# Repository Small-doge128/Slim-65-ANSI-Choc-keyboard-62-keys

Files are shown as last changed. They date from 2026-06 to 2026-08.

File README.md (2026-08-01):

# about

A mint sounding keyboard that's small, lightweight and thin as a cookie, also the hardest was that I used ki cad , building a keyboard and software all of that first in my life. It's going to be for my acer aspire 5. 

# features

Hot swap sockets so you can swap switches fast and easy. You can program the keys to what ever you want via QMK, if you know what are you doing. Custom 3d prnted keycaps that i designed myself except the 1u I bought those and a 3d printed case that you can use but i didn't.

# step by step tutorial for firmware

1. Download the file called slim65_default.uf2.
2. Press and hold the boot button, while holding plug a USB-C cable from your computer to the controller.
3. Now a new folder/device should pop up.
4. Put the .uf2 file into there and it should remove it self.
5. If it did now the keyboard should work enjoy.

# dimensions
PCB - 294 mm lenght and 91 mm width

# keys

it has 49-1U keys, 6-1.25U keys, 2-1.5U keys, 2-1.75U keys, 2-2.25 and  1-6.25U key total 62 keys.

# why did i create it

I created this becouse i wanted a keyboard that i would like and enjoy. It's going to be a massive upgrade from my scissor keyboard on my laptop. I chose slim and 65% keyboard becouse i want it to be compact and light weight. I also like doing projects but this one is something else.

# pictures

2026-05-09-193907_hyprshot



2026-05-09-194605_hyprshot





2026-06-12-214342_hyprshot

2026-06-12-214249_hyprshot

# demo video

https://github.com/user-attachments/assets/ab127268-83f5-4e21-8910-376c34ff119f
This was my first demo video, so excuse my english and my stuttering.

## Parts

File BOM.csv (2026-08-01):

Name | Purpose | Qty | Unit Price (USD) | Total (USD) | Distributor | Link
Keyboard PCB | Connecting all the components | 5 | 5.80 | 29.00 | JLCPCB | https://jlcpcb.com
rp2040-zero | A small brain for the whole system | 1 | 1.99 | 1.99 | Aliexpress | https://www.aliexpress.com/item/1005010194358457.html
Kailh Choc Hotswap Sockets | Socket to swap switches so much faster | 100 | 0.09 | 8.58 | Aliexpress | https://www.aliexpress.com/item/1005008879295483.html
rmRecommeKailh Choc Low Profile Keycaps Black | A bigger surface to type on | 70 | 0.26 | 18.53 | Aliexpress | https://www.aliexpress.com/item/1005009278324475.html
Kailh Choc Low Profile Switch 1350 Red | Switch for keys | 70 | 0.38 | 26.59 | Aliexpress | https://www.aliexpress.com/item/1005008806799106.html
TOTAL |  |  |  | $84.69
TOTAL (with tax & shipping) |  |  |  | $92.69

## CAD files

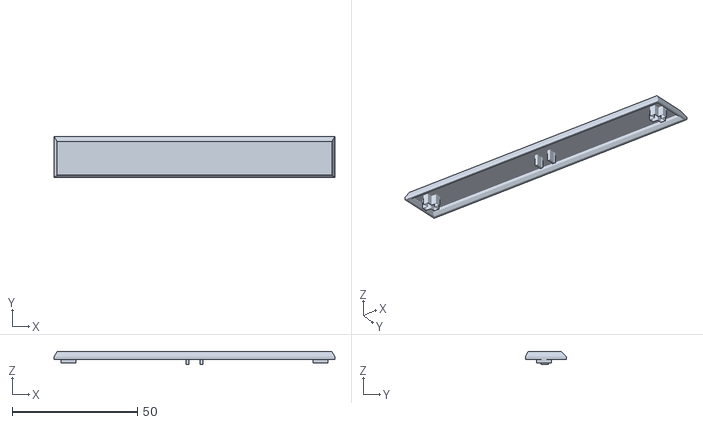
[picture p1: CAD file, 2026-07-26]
kailh choc keycaps/choc keycap 6.25 u.stl
112.0 x 16.5 x 5.00

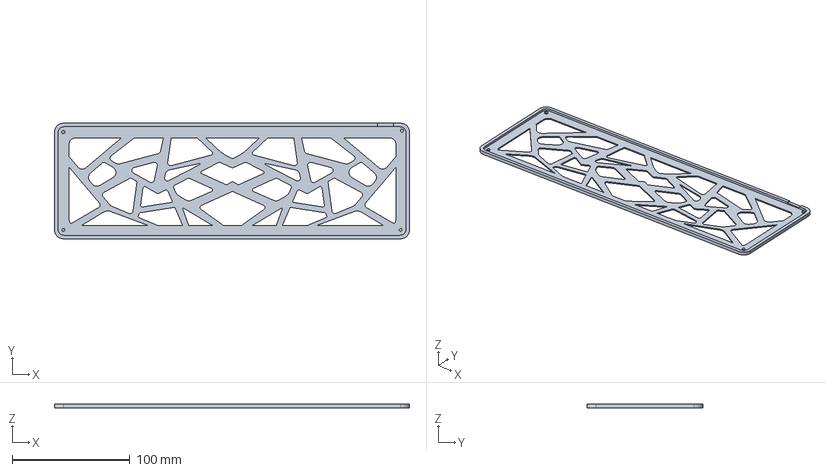
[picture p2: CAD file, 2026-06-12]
step file/Keyboard case.step
301.0 x 98.0 x 3.00 mm

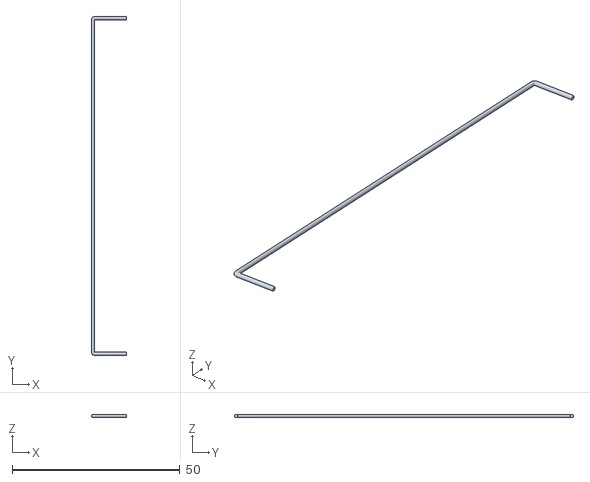
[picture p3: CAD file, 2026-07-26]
kailh choc keycaps/kailh choc stabilizer wire 6.25 u.stl
10.5 x 101.0 x 1.00

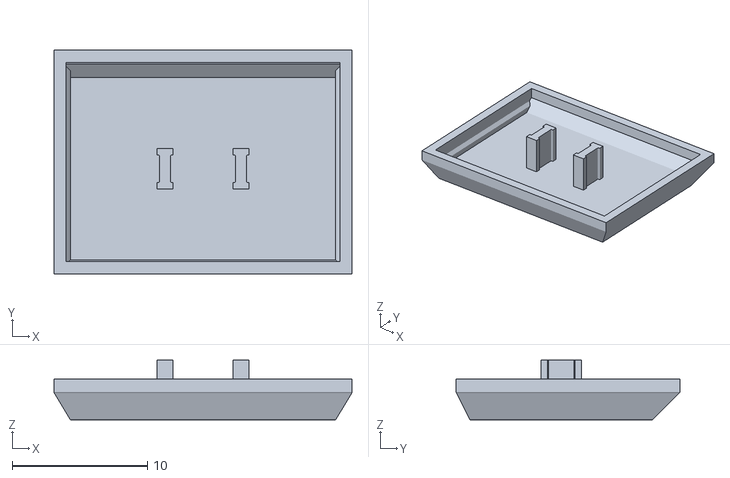
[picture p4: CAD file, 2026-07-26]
kailh choc keycaps/choc keycap 1.25 u.stl
22.0 x 16.5 x 4.40

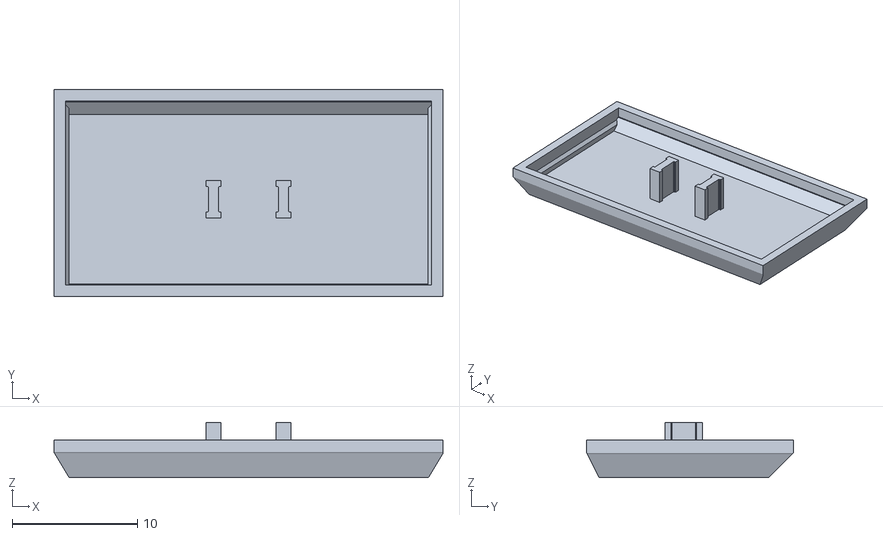
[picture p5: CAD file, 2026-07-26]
kailh choc keycaps/choc keycap 1.75 u.stl
31.0 x 16.5 x 4.40

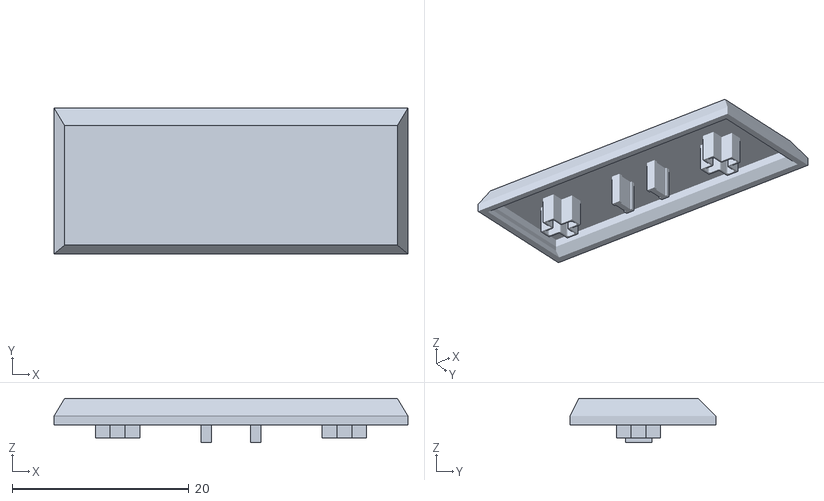
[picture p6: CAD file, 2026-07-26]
kailh choc keycaps/choc keycap 2.25 u.stl
40.0 x 16.5 x 5.00

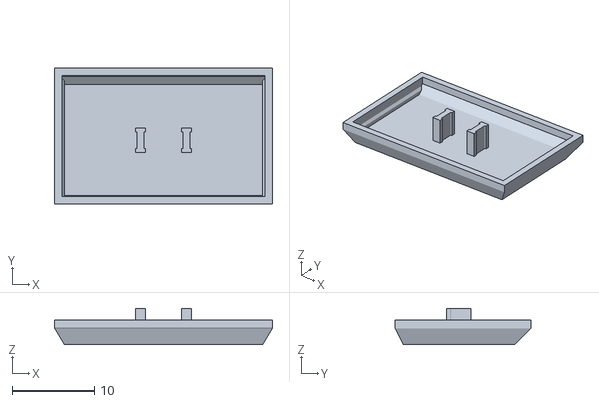
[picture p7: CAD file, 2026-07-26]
kailh choc keycaps/choc keycap 1.5 u.stl
26.5 x 16.5 x 4.40

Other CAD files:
Keyboard case.stl

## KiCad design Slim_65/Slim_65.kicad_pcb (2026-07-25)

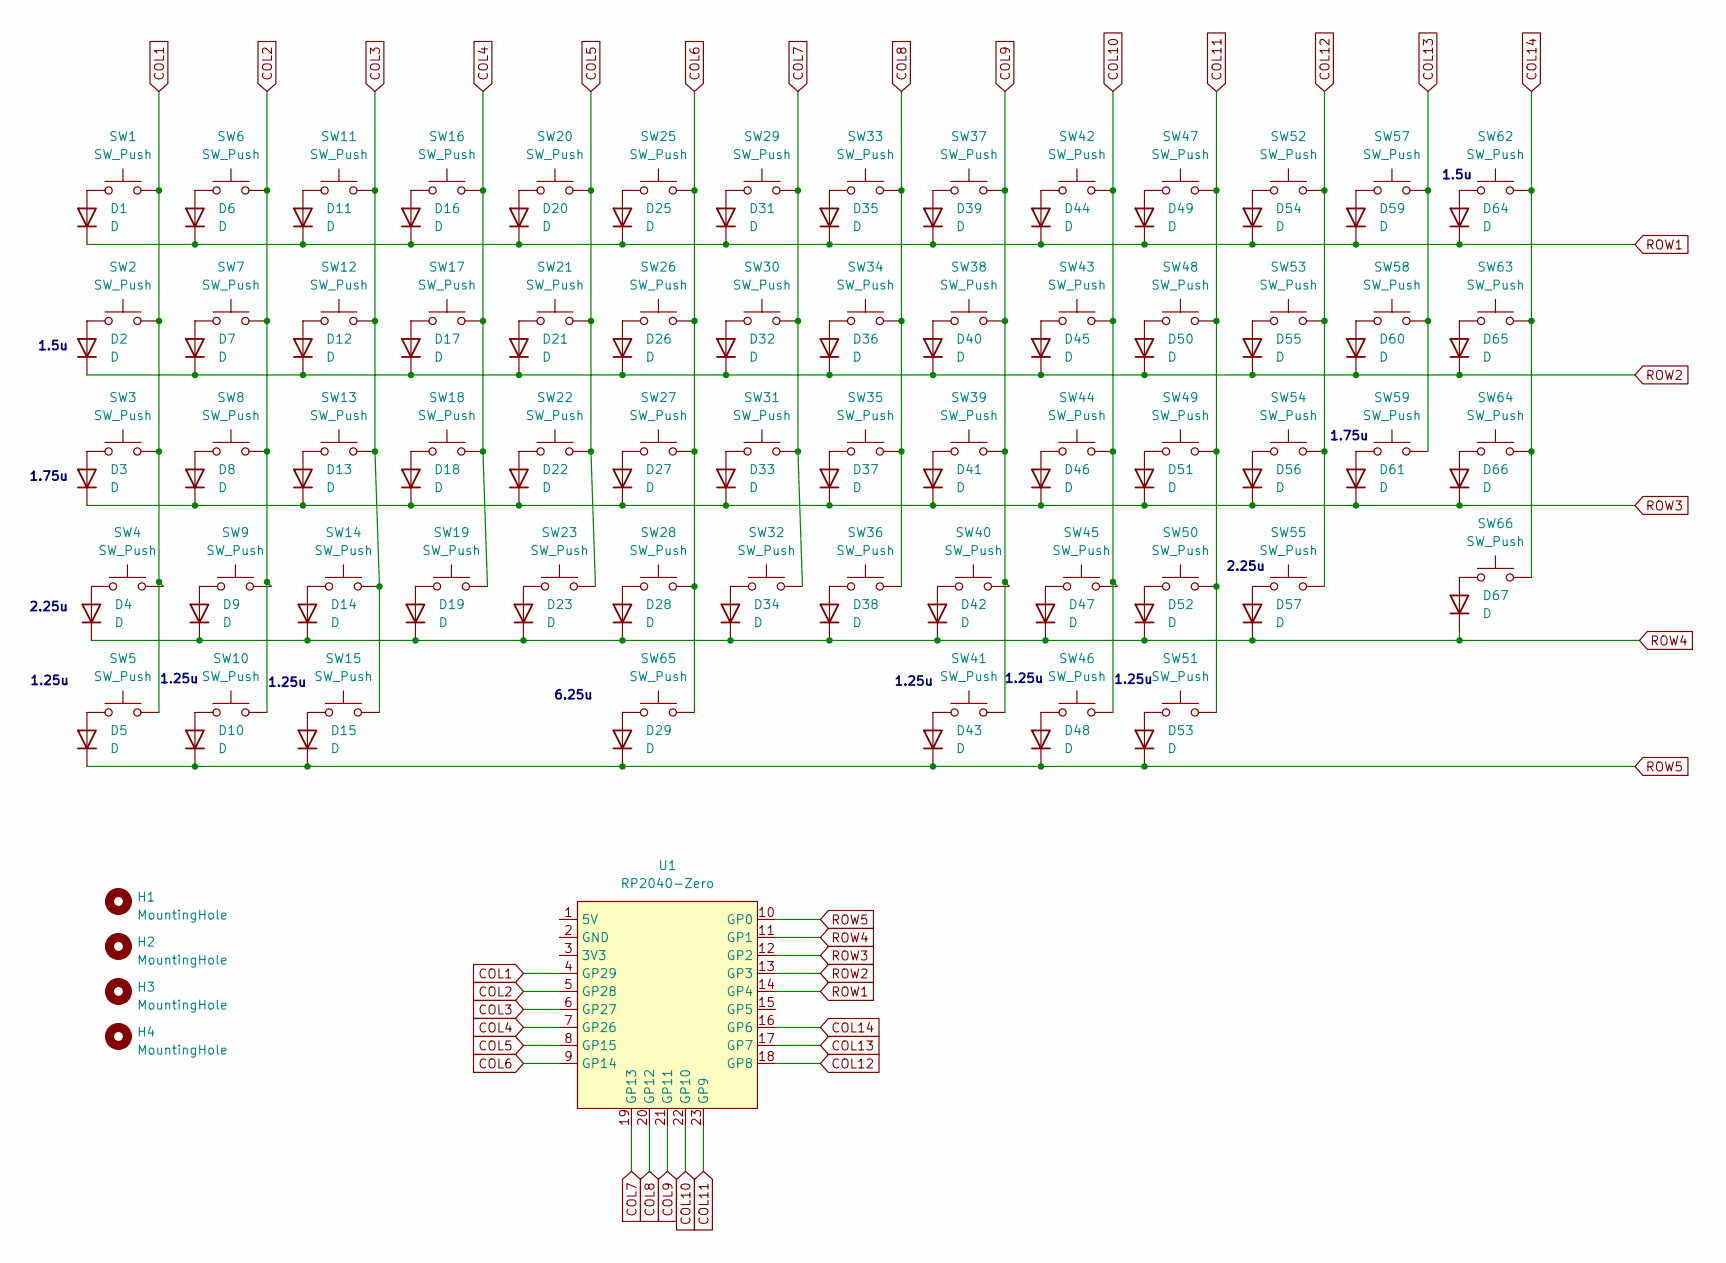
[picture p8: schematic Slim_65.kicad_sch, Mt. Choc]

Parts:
D1, D2, D3, D4, D5, D6, D7, D8, D9, D10, D11, D12, D13, D14, D15, D16, D17, D18, D19, D20, D21, D22, D23, D25, D26, D27, D28, D29, D31, D32, D33, D34, D35, D36, D37, D38, D39, D40, D41, D42, D43, D44, D45, D46, D47, D48, D49, D50, D51, D52, D53, D54, D55, D56, D57, D59, D60, D61, D64, D65, D66, D67: D; D_SOD123
H1, H2, H3, H4: MountingHole; m2_standoff
SW1, SW6, SW7, SW8, SW9, SW11, SW12, SW13, SW14, SW16, SW17, SW18, SW19, SW20, SW21, SW22, SW23, SW25, SW26, SW27, SW28, SW29, SW30, SW31, SW32, SW33, SW34, SW35, SW36, SW37, SW38, SW39, SW40, SW42, SW43, SW44, SW45, SW47, SW48, SW49, SW50, SW52, SW53, SW54, SW57, SW58, SW63, SW64, SW66: SW_Push; Choc-1u
SW2, SW62: SW_Push; Choc-1.5u
SW3, SW59: SW_Push; Choc-1.75u
SW4, SW55: SW_Push; Choc-2.25u
SW5, SW10, SW15, SW41, SW46, SW51: SW_Push; Choc-1.25u
SW65: SW_Push; Choc-6.25u
U1: RP2040-Zero; RP2040 Zero

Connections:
COL1: SW1.2, SW2.2, SW3.2, SW4.2, SW5.2, U1.4 (GP29)
COL2: SW6.2, SW7.2, SW8.2, SW9.2, SW10.2, U1.5 (GP28)
COL3: SW11.2, SW12.2, SW13.2, SW14.2, SW15.2, U1.6 (GP27)
COL4: SW16.2, SW17.2, SW18.2, SW19.2, U1.7 (GP26)
COL5: SW20.2, SW21.2, SW22.2, SW23.2, U1.8 (GP15)
COL6: SW25.2, SW26.2, SW27.2, SW28.2, SW65.2, U1.9 (GP14)
COL7: SW29.2, SW30.2, SW31.2, SW32.2, U1.19 (GP13)
COL8: SW33.2, SW34.2, SW35.2, SW36.2, U1.20 (GP12)
COL9: SW37.2, SW38.2, SW39.2, SW40.2, SW41.2, U1.21 (GP11)
COL10: SW42.2, SW43.2, SW44.2, SW45.2, SW46.2, U1.22 (GP10)
COL11: SW47.2, SW48.2, SW49.2, SW50.2, SW51.2, U1.23 (GP9)
COL12: SW52.2, SW53.2, SW54.2, SW55.2, U1.18 (GP8)
COL13: SW57.2, SW58.2, SW59.2, U1.17 (GP7)
COL14: SW62.2, SW63.2, SW64.2, SW66.2, U1.16 (GP6)
unnamed: D1.2 (A), SW1.1
unnamed: D2.2 (A), SW2.1
unnamed: D3.2 (A), SW3.1
unnamed: D4.2 (A), SW4.1
unnamed: D5.2 (A), SW5.1
unnamed: D6.2 (A), SW6.1
unnamed: D7.2 (A), SW7.1
unnamed: D8.2 (A), SW8.1
unnamed: D9.2 (A), SW9.1
unnamed: D10.2 (A), SW10.1
unnamed: D11.2 (A), SW11.1
unnamed: D12.2 (A), SW12.1
unnamed: D13.2 (A), SW13.1
unnamed: D14.2 (A), SW14.1
unnamed: D15.2 (A), SW15.1
unnamed: D16.2 (A), SW16.1
unnamed: D17.2 (A), SW17.1
unnamed: D18.2 (A), SW18.1
unnamed: D19.2 (A), SW19.1
unnamed: D20.2 (A), SW20.1
unnamed: D21.2 (A), SW21.1
unnamed: D22.2 (A), SW22.1
unnamed: D23.2 (A), SW23.1
unnamed: D25.2 (A), SW25.1
unnamed: D26.2 (A), SW26.1
unnamed: D27.2 (A), SW27.1
unnamed: D28.2 (A), SW28.1
unnamed: D29.2 (A), SW65.1
unnamed: D31.2 (A), SW29.1
unnamed: D32.2 (A), SW30.1
unnamed: D33.2 (A), SW31.1
unnamed: D34.2 (A), SW32.1
unnamed: D35.2 (A), SW33.1
unnamed: D36.2 (A), SW34.1
unnamed: D37.2 (A), SW35.1
unnamed: D38.2 (A), SW36.1
unnamed: D39.2 (A), SW37.1
unnamed: D40.2 (A), SW38.1
unnamed: D41.2 (A), SW39.1
unnamed: D42.2 (A), SW40.1
unnamed: D43.2 (A), SW41.1
unnamed: D44.2 (A), SW42.1
unnamed: D45.2 (A), SW43.1
unnamed: D46.2 (A), SW44.1
unnamed: D47.2 (A), SW45.1
unnamed: D48.2 (A), SW46.1
unnamed: D49.2 (A), SW47.1
unnamed: D50.2 (A), SW48.1
unnamed: D51.2 (A), SW49.1
unnamed: D52.2 (A), SW50.1
unnamed: D53.2 (A), SW51.1
unnamed: D54.2 (A), SW52.1
unnamed: D55.2 (A), SW53.1
unnamed: D56.2 (A), SW54.1
unnamed: D57.2 (A), SW55.1
unnamed: D59.2 (A), SW57.1
unnamed: D60.2 (A), SW58.1
unnamed: D61.2 (A), SW59.1
unnamed: D64.2 (A), SW62.1
unnamed: D65.2 (A), SW63.1
unnamed: D66.2 (A), SW64.1
unnamed: D67.2 (A), SW66.1
ROW1: D1.1 (K), D6.1 (K), D11.1 (K), D16.1 (K), D20.1 (K), D25.1 (K), D31.1 (K), D35.1 (K), D39.1 (K), D44.1 (K), D49.1 (K), D54.1 (K), D59.1 (K), D64.1 (K), U1.14 (GP4)
ROW2: D2.1 (K), D7.1 (K), D12.1 (K), D17.1 (K), D21.1 (K), D26.1 (K), D32.1 (K), D36.1 (K), D40.1 (K), D45.1 (K), D50.1 (K), D55.1 (K), D60.1 (K), D65.1 (K), U1.13 (GP3)
ROW3: D3.1 (K), D8.1 (K), D13.1 (K), D18.1 (K), D22.1 (K), D27.1 (K), D33.1 (K), D37.1 (K), D41.1 (K), D46.1 (K), D51.1 (K), D56.1 (K), D61.1 (K), D66.1 (K), U1.12 (GP2)
ROW4: D4.1 (K), D9.1 (K), D14.1 (K), D19.1 (K), D23.1 (K), D28.1 (K), D34.1 (K), D38.1 (K), D42.1 (K), D47.1 (K), D52.1 (K), D57.1 (K), D67.1 (K), U1.11 (GP1)
ROW5: D5.1 (K), D10.1 (K), D15.1 (K), D29.1 (K), D43.1 (K), D48.1 (K), D53.1 (K), U1.10 (GP0)

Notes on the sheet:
1.5u
1.25u
6.25u
2.25u
1.75u

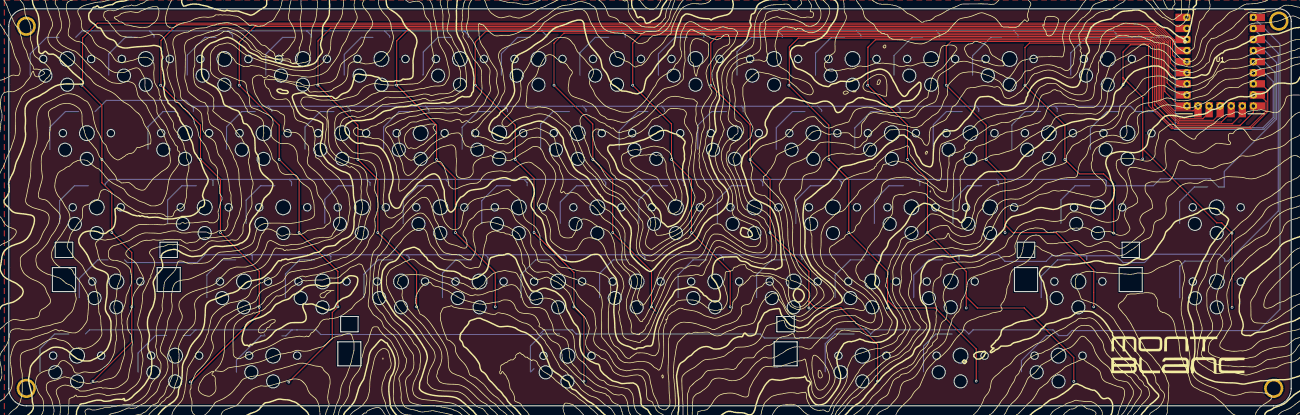
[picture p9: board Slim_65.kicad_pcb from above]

Board: 2 copper layers, 293.9 x 91.0 mm, 130 parts (0 on the bottom side), 81 nets.

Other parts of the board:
g```: LOGO; mont

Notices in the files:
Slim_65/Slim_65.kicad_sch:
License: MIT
